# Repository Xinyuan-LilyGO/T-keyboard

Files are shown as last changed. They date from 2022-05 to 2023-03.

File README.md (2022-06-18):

<h1 align = "center">🌟LILYGO T-keyboard🌟</h1>

## **English | [中文](./README_CN.MD)**

<h3 align = "left">Default some custom functions:</h3>

| keyboard input | Trigger |
| :---: | :---: |
| Left shit | Shift |
| Right shit | Toggle case locking |
| sym | Enter numbers and characters (only triggered once, not locked) |
| alt+left shit  | ctrl+shift(Switch the input method) |
| alt+b | Change keyboard backlight status |
| ... | More custom features can be modified source code implementation, or feedback |

<h3 align = "left">Quick start:</h3>

**USE Arduino IDE**

1. Install the current upstream Arduino IDE at the 1.8 level or later. The current version is at the [Arduino website](http://www.arduino.cc/en/main/software).
2. Start Arduino and open Preferences window. In additional board manager add url: https://raw.githubusercontent.com/espressif/arduino-esp32/gh-pages/package_esp32_index.json .separating them with commas.
3. Select Tools -> Board -> ESP32C3 Dev Module
4. If you do not have a driver installed, you need to install it (Window:ch341ser2.exe, MAC:ch34x_mac_driver_v1.6.zip [New driver reference](https://github.com/LilyGO/LILYGO-T-OI/issues/3#issuecomment-907645945 ))
5. Need to install the following dependencies
     - [ESP32-BLE-Keyboard](https://github.com/T-vK/ESP32-BLE-Keyboard/tree/0.3.0)
     - [T-0.99TFT](https://github.com/Xinyuan-LilyGO/T-0.99TFT)

**USE PlatformIO**

1. Install[VSCODE](https://code.visualstudio.com/)and[Python](https://www.python.org/)
2. Search for the PlatformIO plug-in in the VSCODE extension and install it.
3. After the installation is complete and the reload is completed, there will be a small house icon in the lower left corner. Click to display the Platformio IDE home page
4. Go to file - > Open folder - > Select the LilyGO-T-Keybord folder and click the (√) symbol in the lower left corner to compile (→) for upload.

<h3 align = "left">Product 📷:</h3>

|  Product | Product  Link |
| :---: | :---: |
| T-keyboard | [AliExpress](https://pt.aliexpress.com/item/1005004182998265.html) |

## Matters need attention 
1. Do not set the screen backlight to too high, which may cause overexposure

## Pinout

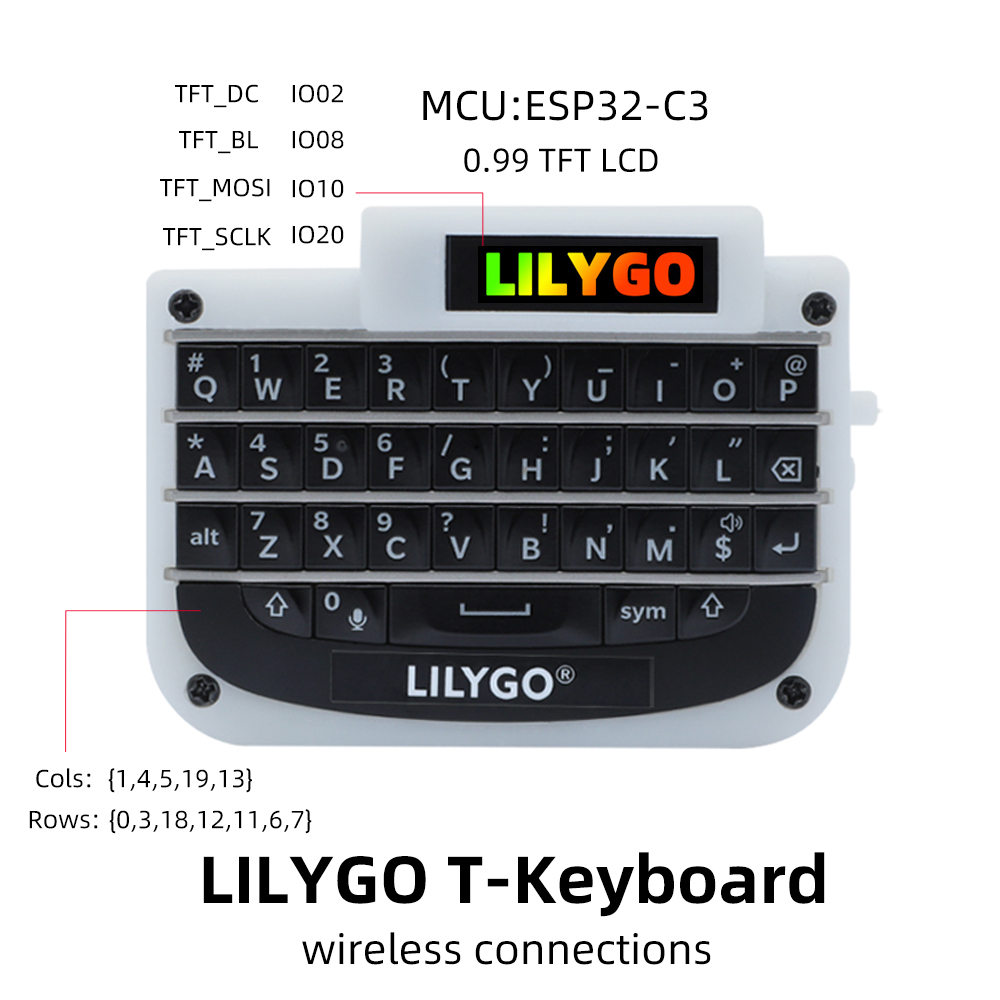
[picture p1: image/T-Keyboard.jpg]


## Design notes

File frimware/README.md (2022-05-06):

<h1 align = "center">🌟LILYGO T-keyboard🌟</h1>

[Flash Download Tool](https://www.espressif.com/en/support/download/other-tools)

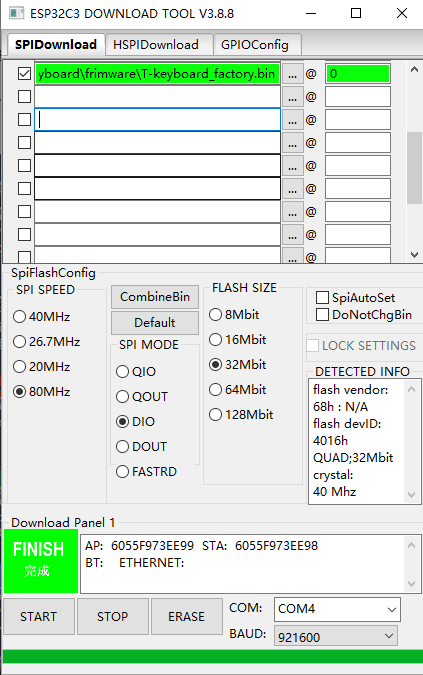
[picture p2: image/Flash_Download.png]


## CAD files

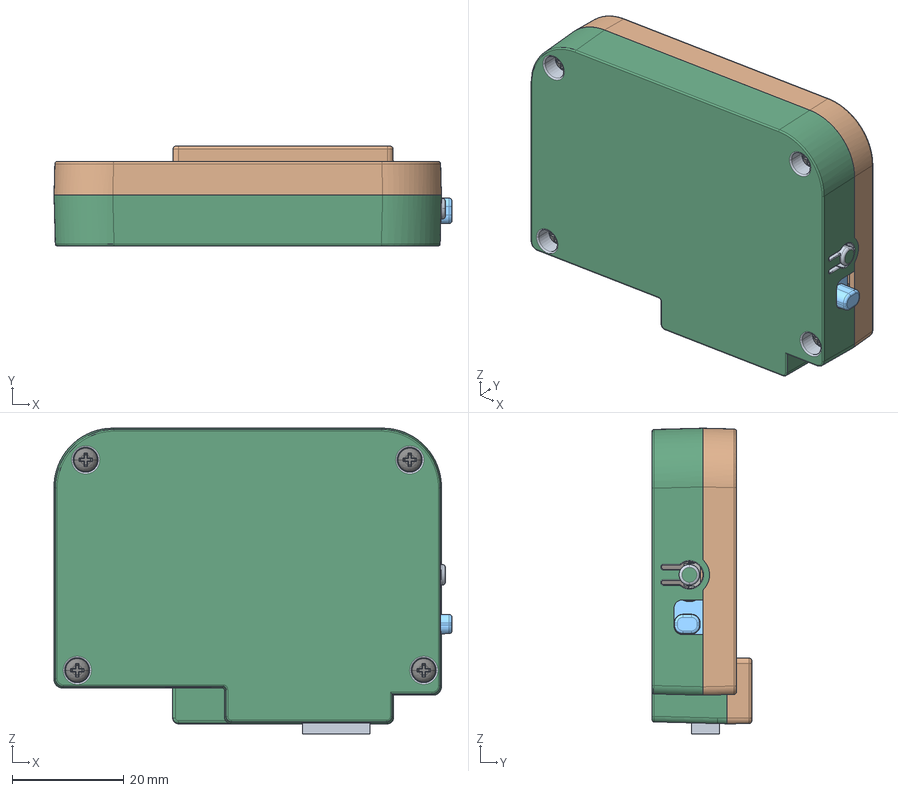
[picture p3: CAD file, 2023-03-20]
3D_file/T-Keyboard.stp
71.1 x 17.8 x 54.6 mm
020_WATCK_KEY_ACOV_2_3
021_WATCK_KEY_BCOV_2_6
022_WATCK_KEY_CCOV_2_1
BRASS_NUTS-2_5_3-2_1 x 4
SCREW_M2-8_1 x 4
MANIFOLD_SOLID_BREP_216_1_1
MANIFOLD_SOLID_BREP_217_1_1
MANIFOLD_SOLID_BREP_220_2_1
WATCH_KEY_LCD_SLOT-B
WATCH_KEY_LCD_SLOT-A

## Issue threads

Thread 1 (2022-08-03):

PCB schematic?

jaksatomovic, 2022-08-03:

SkUrRiEr, 2023-03-13:
As far as I can tell, no schematic has been released anywhere.

This _seems_ to be loosely based on the [T-OI-PLUS](https://github.com/Xinyuan-LilyGO/LilyGo-T-OI-PLUS/) which does have a released schematic.

Based on some brief research, the major changes seem to be:
1. Completely eliminating the analogue input circuitry
2. Connecting almost all the I/O pins to the keyboard, i.e. 12 I/O pins hooked up directly to the columns and rows, and pin 9 hooked to some circuitry to drive the keyboard's backlight
3. Connecting the remaining I/O pins to the [T-0.99-TFT module](https://github.com/Xinyuan-LilyGO/T-0.99TFT) which also contains the expansion connector

The ESP32-C3 has a grand total of 22 available I/O pins including 4-7 for the program flash and 2 for the serial port, leaving a grand total of 13-16 usable pins. We have assignments for 17.

This means that there are simply no I/O pins left to dedicate to the keyboard's microphone or the battery management. Which means that the only way those could be connected to the microcontroller would be if they're doing something _seriously_ tricky to hook these functions up to one of the ADC pins: 0-5.

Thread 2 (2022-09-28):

Compiling error. Can you provide hardware details

vcchm, 2022-09-28:
Hello !

The device is not working after compiling for ESP32C3 Dev module. Can you provide more information about the board : flash size (4 Mb ? 8 Mb) - under arduino you get an error when startipn the module if the flash size is not exactly correct ? Wiring (i want to program a wakeup function, but for this I need to now what wakeup pin i can use) ? Thanks in advance

LilyGO, 2022-09-28:
Hello .Flash size 4MB. No extra pins

vcchm, 2022-09-28:
Thanks ! Could you share the info & wiring of ESP32 on the main page ? Would help lots of users.

LilyGO, 2022-09-28:
https://github.com/Xinyuan-LilyGO/T-keyboard#pinout

Closed 2022-11-02.

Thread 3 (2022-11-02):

Windows 10 & 11 work fine, but challenges connecting to Android

vcchm, 2022-11-02:
Hi ! I compiled the code, pairing & sending keys work well with a PC Windows 10 or 11, but I can't pair with an Android device (Samsung note 20). Here are screenshots. Message reads "Paring with the device impossible. Please ensure that the device is ready for pairing.".

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

LilyGO, 2022-11-03:
Hello. Is it possible to pair with this [firmware?](https://github.com/Xinyuan-LilyGO/T-keyboard/releases/download/T-KeyboardV1.0.0/T-keyboard__factory_1.0.0.bin)

vcchm, 2022-11-03:
I only can flash an arduino sketch, not a binary but if i test the original firmware provided with a new keyboard, it pairs after a couple of atempts. Can you tell me the precise version of the blekeyboard you are using ? It seems that they did modifications that makes it not working for Android in the latest versions...

LilyGO, 2022-11-03:
In the lib

vcchm, 2022-11-03:
No the latesy version is not working - you compiled the code with a former version but you do not tell which version you used in the github. Can you tell me (and other users) the precise version number you used ? The latest has a bug, and i could not find the working version

LilyGO, 2022-11-04:
The library has been modified. It is not a certain version

vcchm, 2022-11-04:
I don't think it has been modified. What happens is that your page should mention the VERSION you are using so that we are sure we use the working version. Do you know what the version is or at least WHEN you compiled the code so that I can use this date's latest version ?

Closed 2022-11-04.

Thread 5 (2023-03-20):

Drivers

allthemod, 2023-03-20:
what do you mean by this(in step 4 for the arduino ide):
If you do not have a driver installed, you need to install it (Window:ch341ser2.exe, MAC:ch34x_mac_driver_v1.6.zip https://github.com/LilyGO/LILYGO-T-OI/issues/3#issuecomment-907645945)

how to install it?
and can i use it on other versions of esp32?

SkUrRiEr, 2023-04-08:
The driver being requested here is the driver for the USB-serial chip, which is a CH340K or equivalent chip.

Closed 2023-04-19.

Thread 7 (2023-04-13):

Unable to compile BLE_Keyboard

Chanete, 2023-04-13:
Hi, I'm trying to compile the BLE_Keyboard  sample.
I followed the instructions (installed latest arduino ide 2.0.4, installed latest usb driver, addded board, selected ESP32C, added the two libs and compile and upload.

Everything seems to be OK, but the keyboard is now locked (nothing on screen)
This is my compiler output.

Thx for your help

`Sketch uses 988408 bytes (75%) of program storage space. Maximum is 1310720 bytes.
Global variables use 57316 bytes (17%) of dynamic memory, leaving 270364 bytes for local variables. Maximum is 327680 bytes.
esptool.py v4.5.1
Serial port COM9
Connecting....
Chip is ESP32-C3 (revision v0.3)
Features: WiFi, BLE
Crystal is 40MHz
MAC: 7c:df:a1:d5:ae:d8
Uploading stub...
Running stub...
Stub running...
Changing baud rate to 921600
Changed.
Configuring flash size...
Flash will be erased from 0x00000000 to 0x00003fff...
Flash will be erased from 0x00008000 to 0x00008fff...
Flash will be erased from 0x0000e000 to 0x0000ffff...
Flash will be erased from 0x00010000 to 0x00108fff...
Compressed 13152 bytes to 9473...
Writing at 0x00000000... (100 %)
Wrote 13152 bytes (9473 compressed) at 0x00000000 in 0.4 seconds (effective 267.3 kbit/s)...
Hash of data verified.
Compressed 3072 bytes to 146...
Writing at 0x00008000... (100 %)
Wrote 3072 bytes (146 compressed) at 0x00008000 in 0.1 seconds (effective 329.8 kbit/s)...
Hash of data verified.
Compressed 8192 bytes to 47...
Writing at 0x0000e000... (100 %)
Wrote 8192 bytes (47 compressed) at 0x0000e000 in 0.2 seconds (effective 435.7 kbit/s)...
Hash of data verified.
Compressed 1019904 bytes to 553498...
Writing at 0x00010000... (2 %)
Writing at 0x0001b21c... (5 %)
Writing at 0x00028388... (8 %)
Writing at 0x000352d2... (11 %)
Writing at 0x000403fd... (14 %)
Writing at 0x00046293... (17 %)
Writing at 0x0004cbef... (20 %)
Writing at 0x000540c8... (23 %)
Writing at 0x0005a325... (26 %)
Writing at 0x0006083a... (29 %)
Writing at 0x00067dec... (32 %)
Writing at 0x0006e40f... (35 %)
Writing at 0x00074d16... (38 %)
Writing at 0x0007af53... (41 %)
Writing at 0x00081230... (44 %)
Writing at 0x000886be... (47 %)
Writing at 0x0008ee4a... (50 %)
Writing at 0x0009696a... (52 %)
Writing at 0x0009d20d... (55 %)
Writing at 0x000a34e9... (58 %)
Writing at 0x000aa543... (61 %)
Writing at 0x000b1eab... (64 %)
Writing at 0x000baa52... (67 %)
Writing at 0x000c14c2... (70 %)
Writing at 0x000c7d5e... (73 %)
Writing at 0x000ceaf3... (76 %)
Writing at 0x000d5047... (79 %)
Writing at 0x000db14a... (82 %)
Writing at 0x000e0eda... (85 %)
Writing at 0x000e75b5... (88 %)
Writing at 0x000eec7c... (91 %)
Writing at 0x000f8596... (94 %)
Writing at 0x000fdd96... (97 %)
Writing at 0x00103f19... (100 %)
Wrote 1019904 bytes (553498 compressed) at 0x00010000 in 13.7 seconds (effective 597.0 kbit/s)...
Hash of data verified.

Leaving...
Hard resetting via RTS pin...`

allthemod, 2023-04-14:
I had the same problem.
It's like you can't write to there.
Anyway I just used the download flash tools to flash the firmware bin file into the esp.
If you wanna to customize it idk.
But if you wanna to return it back to the default I can help you.

Chanete, 2023-04-19:
I've found a workaround that works, I'm using platformIO instead of Arduino IDE and now I can compile and modify without problems.

Probably there is some setup in arduino ide config missing in the docs.

Thx anyway @allthemod  for your offer.

allthemod, 2023-04-19:
Well I didn't know that.
This is also very handy to me so thank you and have a great day @Chanete .

copykatze, 2023-05-05:
I had the same problem and solved it by changing the "flash mode" in the Arduino IDE from "QUI" to "DOUT". Flashing seems to work fine now. Cheers.

allthemod, 2023-05-05:
Thanks and have a great day.

Adarkk, 2024-06-25:
Hey can someone help me to get taht stuff back to work ?

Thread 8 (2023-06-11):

display initialization problem

copykatze, 2023-06-11:
Sometimes the display does not initialize properly, it will only show some thin lines or a light grey background and it can't be written to by the program. Reseting the device by on/off or the reset button helps sometimes after a few tries, sometimes it seems to need "off-time", but I could not really figure out when it does not work and what gets it back on track. It is really unreliable like this. What might cause this weirdness?

I found that when I enabled core debug level, at `TFT_099.begin();` I get this log:

```
12:51:23.065 -> [   174][E][esp32-hal-gpio.c:102] __pinMode(): Invalid pin selected
12:51:23.097 -> [   174][E][esp32-hal-gpio.c:102] __pinMode(): Invalid pin selected
12:51:23.097 -> [   177][E][esp32-hal-gpio.c:102] __pinMode(): Invalid pin selected
12:51:23.195 -> [   283][E][esp32-hal-spi.c:227] spiAttachMISO(): SPI Does not have default pins on ESP32C3!
```

Could this be the cause of it? But those error messages will also be in the logs when it works. No idea how to debug this any further... :(

Any help appreciated, thanks and cheers!

copykatze, 2023-06-11:
In `TFT_GC9D01N.h`I found

```
#define TFT_MISO  -1
#define TFT_MOSI  10//21
#define TFT_SCLK  20//22
#define TFT_CS    -1//18  // Chip select control pin
#define TFT_DC    2  // Data Command control pin
#define TFT_RST   -1//27
#define TFT_BL    8//4

/*
#define TFT_MISO  -1
#define TFT_MOSI  21
#define TFT_SCLK  22
#define TFT_CS    18  // Chip select control pin
#define TFT_DC    2  // Data Command control pin
#define TFT_RST   27
#define TFT_BL    23//4
*/
```
It seems strange to me that TFT_MISO, TFT_CS and TFT_RST. are all defined -1 (does that mean "undefined?) and I wonder what that commented block of alternative definitions is all about...

copykatze, 2023-06-11:
Another observation: what seems to help is to power it on while connected to usb c power and then pressing the reset button. This method does not help without the device being plugged in.

So maybe the small battery does not provide enough power for the (tiny) display? But on the other side, the grey screen happens also while powering on when plugged in sometimes...

alejovargas78, 2024-01-22:
Hello, I had the same problem, the solution is simple.

Open the library TFT_GC9D01N.cpp and disable the following lines

int TFT_GC9D01N_Class::begin()
{
     pinMode(TFT_BL, OUTPUT);
     pinMode(TFT_SCLK, OUTPUT);
     //pinMode(TFT_MISO, OUTPUT);
     pinMode(TFT_MOSI, OUTPUT);
     pinMode(TFT_DC, OUTPUT);
     //pinMode(TFT_CS, OUTPUT);
     //pinMode(TFT_RST, OUTPUT);

Greetings from Bogota Col.

copykatze, 2024-01-22:
Wow, thank you so much, @alejovargas78 !! I did not get an external display working (yet), but I am happy to hear that it seems to be possible :)

Could you share with me which kind of display you were able to connect and how you wired it exactly?

I am trying with a ili9341 ("2.2 TFT SPI 240*320") display.

My wiring, after editing the library according to your suggestion, is

Display <-> T-Keyboard

SDO (MISO) <->
LEDK <->LED
SCK <-> SCL
SDI (MOSI) <-> SDA
D/C <-> D/C
RESET <->
CS <->
GND <-> GND
VCC <-> +3.3V

Running the [TFT_Demo.ino](https://github.com/Xinyuan-LilyGO/T-keyboard/blob/main/lib/T-0.99TFT/examples/TFT_Demo/TFT_Demo.ino) example, the display just  flickers a bit.

One error I see on the serial monitor is:
`[   192][E][esp32-hal-spi.c:227] spiAttachMISO(): SPI Does not have default pins on ESP32C3!`

It would be so awesome if I could finish this project afterall :)

copykatze, 2024-01-23:
Unfortunately, I have the same result/problem with the adjustments in the library, still thanks for the suggestion!

alejovargas78, 2024-09-07:
pinMode(TFT_MOSI, OUTPUT);
    pinMode(TFT_DC, OUTPUT);
    pinMode(TFT_BL, OUTPUT);
    pinMode(TFT_SCLK, OUTPUT);
    ledcSetup(1, 1000, 10);
    ledcAttachPin(TFT_BL, 1);
    ledcWrite(1, 0);
    delay(100);

    SPI.begin(TFT_SCLK, TFT_MISO, TFT_MOSI, TFT_CS);

    int i = 2;
    while (i--) {
        lcd_init();
        delay(200); /* code */
    }
    ledcWrite(1, 220);//开启背光

    return 1;

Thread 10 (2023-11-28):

working like a Blackberry Keyboard

Flexmaen, 2023-11-28:
Hi!

Great hardware, however for me it's a bit confusing that this keyboard does look like a Blackberry-Keyboard, but doesn't work like one.

This means:
- ALT-Key usually does all the other signs shown on the keyboard, not sym.
Numbers, ,?/().,' etc. is all done by alt key.
- Alt-Key works as long as you hold it down, that means just jold it down and type numbers instead having to press it every time you write a number.
- Sym key can be configured for international options. E.g. sym+u = ü.
- right shift key can be configured as normal shift key or as ctrl-key which means that witch ctrl+c and v you can copy and paste things. (maybe it also makes sense to use the sym-key here instead).

slayinturds, 2023-12-21:
So it does work like a blackberry keyboard or not exactly? It's been ages since I had my bold 5000, and I'm just trying to have that magic back via Bluetooth. Is this the device for the job?

Flexmaen, 2023-12-22:
It doesn't even come close to a Blackberry keyboard although it is a keyboard of the Q10.
But the way it works is completely messed up.
Like I said: Alt and Sym Key are confused, holding down the alt/sym-Key has no effect, so typing numbers is a pain.

So if you ever used a Blackberry keyboard, then this device is a big disappointment. Depending on what you need this for, you might take a look on the BBQ20KBD or Help2Type.

However, the good thing: Most things could be fixed via software, that's why I opened this issue here.

slayinturds, 2023-12-24:
That makes sense, thanks for the suggestion. Hopefully they figure out the software since I already ordered one

zenkalia, 2023-12-27:
I just bought one because fixing some keybinds seems easier than taking the BBQ and connecting it to a battery and BLE module for my use case (typing with baby asleep on me).

I'll be taking a look at this when mine comes. At a glance, the right shift seems easiest to fix. Other language support seems daunting and the other modifiers seem somewhere in between. Thankfully the shift issue is the most important to me!

slayinturds, 2023-12-27:
I hate it. I'll be taking it back and if they refuse I'll go to their
office in Gainesville FL. I live there conincidentally. If it's possible
I'll share feeeback directly. The keys for one are at the same level as the
case and the trim pieces, making it so difficult to land on the keys and
not the case elements when inputting characters. That is such a no brainer
to fix and figure out when prototyping

On Wed, Dec 27, 2023, 11:28 AM Mike Kendall ***@***.***>
wrote:

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

zenkalia, 2023-12-28:
That's too bad! Mine hasn't come yet and the ergonomics of those bars does worry me. This is the best option out there since the Help2Type is so expensive that you might as well buy a palmtop computer.

slayinturds, 2023-12-28:
Yeah it is.
Honestly, I'm interested in this one next that you suggested:
https://shop.pimoroni.com/products/bbq20-keyboard-with-trackpad-usb-i2c-pmod?variant=39913457188947

On Thu, Dec 28, 2023 at 2:43 PM Mike Kendall ***@***.***>
wrote:

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

Flexmaen, 2023-12-29:
What are you planning to use it for? I didn't test the BBQ20, but I'm currently using the Help2Type for my phone. The flip-mechanism works better than I thought it will. The downside compared to a Blackberry keyboard is that keys are harder to press, and the lack of the ctrl-key. The layout is a bit different and some things like the delete key need a bit to adjust. But otherwise the layout is in full accordance with the virtual keyboards that gboard or iOS provide, so it's not a stupid change in the layout. All in all, for me it was worth buying it.

I'm using the T-Keyboard for my Fire-TV now. For occasional typing it's better than the remote control, but that's it.
Sure this is a rather cheap solution, but now I'm not the only one who is surprised how bad a Blackberry keyboard can be if you get the software and the case wront.

slayinturds, 2023-12-29:
With the phone propped up by the kickstand ring on the back of the phone,
and the keypad detached in my hand, I thought I could type emails better
when away from my computer. That may not be the case. I used to be able to
type for a long time for emails with my BB5000, but I'm probably chasing a
time that is irrelevant. I was thinking about your situation and not
wanting to make sound the other day, because I just purchased a Logitech
wireless mouse that makes no clicking sound. I thought I'd hate it but
actually I love it; the M650. I see your uses, that makes sense. The
Help2type, looks ergonomic but I could not deal with the hard key pressing.
I'm so picky with this stuff, I don't mind searching for the perfect
solution to all my problems.

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

zenkalia, 2024-01-05:
Just opened my first PR to this end: https://github.com/Xinyuan-LilyGO/T-keyboard/pull/11

Next comes swapping `alt` and `sym` and adding arrow keys. I'm thinking sym + WASD because it's just too painful not having arrow keys.

And a note on ergonomics: I don't mind the bars between the rows but the case itself IS a little too tall. It should have had a bevel or something because as it is, the keys that are near the case are a little difficult to press.

zenkalia, 2024-01-05:
Alright I got a little overzealous last night and finished it. ALT and SYM swapped and WASD arrow keys:

https://github.com/zenkalia/T-keyboard/tree/alt_sym_arrows

This is what I'm running on my T-Keyboard right now and it's much more fluid than the default behavior. 👍

ibrand, 2024-01-05:
@zenkalia very cool, I just got my T-keyboard in the mail, started searching around for this and was lucky enough to find your comment from just a few hours ago. If I were to use your fork, would I follow the Arduino IDE setup flow and then import your example files? How did you set your keyboard up with alternative code?

thanks for your work on this 🎉

zenkalia, 2024-01-06:
I used the vs code instructions. The arduino IDE was way less fleshed out from what I could tell.

There's also a necessary driver for pushing to the serial port of the device (chx something) which was terrifying to install but it worked. Would love to have that come with the PlayformIO board config or have LILYGO bless it in the readme.

zenkalia, 2024-01-06:
Yeah I've been thinking about how to best handle custom keys since they're different for everyone. I think the right move is to have an extra mapping matrix for symbols that people can modify in code. If you leave a given cell empty then it can be a fully custom function (see backlight toggle).

If there are ever enough users to justify menus and stuff then we'll need to change from the 8x20 font to an 8x10 so that we can display 4 rows rather than 2... Also need a better way to render stuff to the screen since the TFT library isn't going to give us scrolling, for example.

I plan on adding the symbol mapping matrix later today since it's a more elegant and extensible way to add arrow keys.

After that on my todo list is using both rows on the TFT screen when typing.

Also the lack of key repeat is driving me nuts!

zenkalia, 2024-01-14:
@Flexmaen So I did put in a mapping table for the sym key until I realized that those other special characters don't exist in the font. Also I have no idea how this font works to add them. 🤔

zenkalia, 2024-01-14:
Ok. I know how the font works. It's kind of bonkers.

So the font file is a bunch of bitmaps. Here's A: https://github.com/Xinyuan-LilyGO/T-keyboard/blob/main/lib/T-0.99TFT/src/Fonts.h#L38-L39 each hex pair is a row in the character. Each bit is a pixel being on or off.

We write text to the screen using `TFT_099.DispStr`. Each character in that function is then converted from ascii value to "ord" like we see in that font file. The helper function that does that is here: https://github.com/Xinyuan-LilyGO/T-keyboard/blob/main/lib/T-0.99TFT/src/TFT_GC9D01N.cpp#L533-L550 .

So, for every character that you want to add, you have to add it to this conversion helper and to the font bitmask. How much work would it be to make this font array indexed by ascii value instead of "ord" value? 🤯

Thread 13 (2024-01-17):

Any reason why this won't connect to an Apple Watch?

edwardrossi, 2024-01-17:
As far as I know, Bluetooth keyboard's are compatible with Apple Watch, yet I cannot connect the T-keyboard. It doesn't even appear in the Bluetooth devices when in pairing mode.

It's a Series 5 running WatchOS 10.2.

On a side note, it appears and connect flawlessly to iPhone.

For context, I bought the T-Board to connect to my Apple Watch to see how it performs as a dumbphone.
If it passes proof of concept, I will play with some designs and 3D print a case integrating the Apple Watch body and the T-board into a single integrated device.

Any ideas?

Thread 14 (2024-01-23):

How to connect an external display?

copykatze, 2024-01-23:
I could not get an external display working on the "expansion interface". What kind of display can be used and how to wire it?

I am trying with a ili9341 ("2.2 TFT SPI 240*320") display, which I can get working without any problem on other esp/arduino boards, so the display is not broken.

My wiring is

Display <-> T-Keyboard

SDO (MISO) <->
LEDK <->LED
SCK <-> SCL
SDI (MOSI) <-> SDA
D/C <-> D/C
RESET <->
CS <->
GND <-> GND
VCC <-> +3.3V

Running the [graphicstest.ino](https://github.com/adafruit/Adafruit_ILI9341/blob/master/examples/graphicstest/graphicstest.ino) example, the display just  flickers a bit and seems to crash very early, as it does not even Serial.println("ILI9341 Test!"). One error I see on the serial monitor is:

`[   192][E][esp32-hal-spi.c:227] spiAttachMISO(): SPI Does not have default pins on ESP32C3!`

Any help on debugging this (or telling me any stupid mistakes I made) would be highly appreciated, also any info that this has been successfully done by anyone :)

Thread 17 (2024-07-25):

Wont stay connected, and does not work at all under Windows 10

JimDrewGH, 2024-07-25:
So, I got the LilyGO T-Keyboard, powered it on and went to the BLE config under Windows 10 and was able to pair the device.  After that, there is no "keyboard" functionality.  The device also will periodically disconnect and say "Wait bluetooth...." and then finally connect.

I plugged the T-Keyboard into a USB port and pulled up a terminal program and see this constantly (as fast as the serial console will display at 115200 baud):

[2319993][E][BLECharacteristic.cpp:537] notify(): << esp_ble_gatts_send_ notify: rc=-1 Unknown ESP_ERR error

So, does this mean that the T-Keyboard is not compatible with Windows?  I tried the PC motherboard's built-in Bluetooth and an external Bluetooth (USB) device, and both had the same issue.  Ironically, this works flawless with my iPhone13 so I know the T-Keyboard hardware is functional.  This seems like a problem with interfacing to Windows.  Does anyone know why?

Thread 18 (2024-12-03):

language change on PC with T-Keyboard.

Stigjs, 2024-12-03:
Hello
I've never done coding in my life, like VS CODE, but I believe in ChatGPT
I bought a LILYGO T-Keyboard.

I tried to add language conversion (English/Korean) function using GitHub's firmware data and VS code,

The code that ChatGPT corrected keeps making errors..

1. Change the language to the left alt key and enter key. (You can't change the line when you enter.)
2. Set Backlight Time
Backlight off if not entered for 10 seconds. On input back on
3. Delete letters when you press the Backspace key
I don't want to press it repeatedly..
4. Make sure you enter numbers/periods with the left shift key. I asked for these four functions

I kept erasing the original code, so I couldn't do it
I downloaded VS and installed Platformio through ChatGPT
I can't use it because I can't change the language. Please help me..
What should I do?

Stigjs, 2024-12-03:
the Code is..
#define TFT_HIGH  40
#define TFT_WIDE 160
#define GAP 8
#define keyborad_BL_PIN  9

#include "Arduino.h"
#include <SPI.h>
#include "img.h"
#include <TFT_GC9D01N.h>
#include <BleKeyboard.h>

TFT_GC9D01N_Class TFT_099;
BleKeyboard bleKeyboard("T-Keyboard", "ESPRESSIF", 100);

byte rows[] = {0, 3, 18, 12, 11, 6, 7};
const int rowCount = sizeof(rows) / sizeof(rows[0]);

byte cols[] = {1, 4, 5, 19, 13};
const int colCount = sizeof(cols) / sizeof(cols[0]);

bool keys[colCount][rowCount];
bool lastValue[colCount][rowCount];
bool changedValue[colCount][rowCount];

char keyboard[colCount][rowCount];
char keyboard_symbol[colCount][rowCount];

bool symbolSelected = false;
bool isEnglish = true; // 언어 전환 상태
bool alt_active = false;
int OffsetX = 0;
bool keyborad_BL_state = true;
bool display_connected = true;
bool case_locking = false;

unsigned long previousMillis_1 = 0;
unsigned long previousMillis_2 = 0;
const long backlight_off_time = 10000; // 10초
const long display_Wait_blue_time = 2000;

void readMatrix();
bool keyPressed(int colIndex, int rowIndex);
bool keyActive(int colIndex, int rowIndex);
bool isPrintableKey(int colIndex, int rowIndex);
void printMatrix();
void set_keyborad_BL(bool state);
void clear_sccreen();

void setup() {
    Serial.begin(115200);
    Serial.println("Setup started");

    // 키보드 배열 초기화
    keyboard[0][0] = 'q';
    keyboard[0][1] = 'w';
    keyboard[0][2] = '\0'; // Symbol
    keyboard[0][3] = 'a';
    keyboard[0][4] = '\0'; // ALT
    keyboard[0][5] = ' ';
    keyboard[0][6] = '\0'; // Mic

    keyboard[1][0] = 'e';
    keyboard[1][1] = 's';
    keyboard[1][2] = 'd';
    keyboard[1][3] = 'p';
    keyboard[1][4] = 'x';
    keyboard[1][5] = 'z';
    keyboard[1][6] = '\0'; // Left Shift

    keyboard[2][0] = 'r';
    keyboard[2][1] = 'g';
    keyboard[2][2] = 't';
    keyboard[2][3] = '\0'; // Right Shift
    keyboard[2][4] = 'v';
    keyboard[2][5] = 'c';
    keyboard[2][6] = 'f';

    keyboard[3][0] = 'u';
    keyboard[3][1] = 'h';
    keyboard[3][2] = 'y';
    keyboard[3][3] = '\0'; // Enter
    keyboard[3][4] = 'b';
    keyboard[3][5] = 'n';
    keyboard[3][6] = 'j';

    keyboard[4][0] = 'o';
    keyboard[4][1] = 'l';
    keyboard[4][2] = 'i';
    keyboard[4][3] = '\0'; // Backspace
    keyboard[4][4] = '$';
    keyboard[4][5] = 'm';
    keyboard[4][6] = 'k';

    delay(500);
    pinMode(keyborad_BL_PIN, OUTPUT);
    set_keyborad_BL(keyborad_BL_state);

    bleKeyboard.begin();

    for (int x = 0; x < rowCount; x++) {
        pinMode(rows[x], INPUT);
    }

    for (int x = 0; x < colCount; x++) {
        pinMode(cols[x], INPUT_PULLUP);
    }

    TFT_099.begin();
    TFT_099.backlight(50);
    TFT_099.DispColor(0, 0, TFT_WIDTH, TFT_HEIGHT, BLACK);
    TFT_099.DispStr((char*)"Setup completed", 0, 2, WHITE, BLACK); // char*로 캐스팅
    Serial.println("Setup completed");
}

void loop() {
    if (bleKeyboard.isConnected()) {
        readMatrix();

        // ALT(4,0) + ENTER(3,3) 언어 전환
        if (keyActive(4, 0) && keyPressed(3, 3)) {
            isEnglish = !isEnglish;
            TFT_099.DispStr(isEnglish ? (char*)"English Mode" : (char*)"Korean Mode", 0, 2, WHITE, BLACK);
            Serial.println(isEnglish ? "English Mode" : "Korean Mode");
            delay(500);
        }

        // 백라이트 제어
        if (millis() - previousMillis_1 > backlight_off_time) {
            TFT_099.backlight(0);
        }

        printMatrix();

        // Backspace 키 동작
        if (keyPressed(4, 3)) {
            if (OffsetX > 0) OffsetX -= GAP;
            TFT_099.DispColor(0, OffsetX, TFT_HIGH, TFT_WIDE, BLACK);
            bleKeyboard.press(KEY_BACKSPACE);
            bleKeyboard.releaseAll();
        }

        // Left Shift 키로 특수문자 입력
        if (keyActive(1, 6)) {
            case_locking = true;
        } else {
            case_locking = false;
        }

    } else {
        if (millis() - previousMillis_2 > display_Wait_blue_time) {
            TFT_099.DispStr((char*)"Waiting for Bluetooth...", 0, 2, WHITE, BLACK); // char*로 캐스팅
            display_connected = true;
            previousMillis_2 = millis();
        }
    }
}

void readMatrix() {
    for (int colIndex = 0; colIndex < colCount; colIndex++) {
        for (int rowIndex = 0; rowIndex < rowCount; rowIndex++) {
            bool currentValue = digitalRead(cols[colIndex]) == LOW && digitalRead(rows[rowIndex]) == LOW;
            if (currentValue != lastValue[colIndex][rowIndex]) {
                changedValue[colIndex][rowIndex] = true;
            } else {
                changedValue[colIndex][rowIndex] = false;
            }
            keys[colIndex][rowIndex] = currentValue;
            lastValue[colIndex][rowIndex] = currentValue;
        }
    }
}

bool keyPressed(int colIndex, int rowIndex) {
    return changedValue[colIndex][rowIndex] && keys[colIndex][rowIndex];
}

bool keyActive(int colIndex, int rowIndex) {
    return keys[colIndex][rowIndex];
}

bool isPrintableKey(int colIndex, int rowIndex) {
    return keyboard[colIndex][rowIndex] != '\0';
}

void printMatrix() {
    for (int rowIndex = 0; rowIndex < rowCount; rowIndex++) {
        for (int colIndex = 0; colIndex < colCount; colIndex++) {
            if (keyPressed(colIndex, rowIndex)) {
                String key = String(keyboard[colIndex][rowIndex]);
                if (case_locking) key.toUpperCase();
                Serial.print(key);
                bleKeyboard.print(key);
                OffsetX += GAP;
                if (OffsetX > 160) {
                    OffsetX = 0;
                    clear_sccreen();
                }
            }
        }
    }
}

void set_keyborad_BL(bool state) {
    digitalWrite(keyborad_BL_PIN, state);
}

void clear_sccreen() {
    TFT_099.DispColor(0, 0, TFT_HIGH, TFT_WIDE, BLACK);
    OffsetX = 0;
}

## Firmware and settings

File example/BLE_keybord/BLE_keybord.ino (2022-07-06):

#define TFT_HIGH  40
#define TFT_WIDE 160
#define GAP 8
#define keyborad_BL_PIN  9


#include "Arduino.h"
#include <SPI.h>
#include "img.h"
#include<TFT_GC9D01N.h>
TFT_GC9D01N_Class TFT_099;

#include <BleKeyboard.h>
BleKeyboard bleKeyboard("T-Keyboard", "ESPRESSIF", 100);

byte rows[] = {0, 3, 18, 12, 11, 6, 7};
const int rowCount = sizeof(rows) / sizeof(rows[0]);


byte cols[] = {1, 4, 5, 19, 13};
const int colCount = sizeof(cols) / sizeof(cols[0]);

bool keys[colCount][rowCount];
bool lastValue[colCount][rowCount];
bool changedValue[colCount][rowCount];

char keyboard[colCount][rowCount];
char keyboard_symbol[colCount][rowCount];


bool symbolSelected;
int OffsetX = 0;
uint16_t flow_i = 0;
bool keyborad_BL_state = true;
bool display_connected = true;  //The bluetooth connection is displayed on the screen
bool case_locking = false;
bool alt_active = false;
unsigned long previousMillis_1 = 0; //Millisecond time record
unsigned long previousMillis_2 = 0; //Millisecond time record
const long backlight_off_time = 20000;       //Turn off the screen backlight
const long display_Wait_blue_time = 2000;       //The screen shows waiting for bluetooth connection

void readMatrix();
bool keyPressed(int colIndex, int rowIndex);
bool keyActive(int colIndex, int rowIndex);
bool isPrintableKey(int colIndex, int rowIndex);
void printMatrix();
void set_keyborad_BL(bool state);
void clear_sccreen();

void setup()
{
    Serial.begin(115200);
    Serial.printf("setup \n");
    keyboard[0][0] = 'q';
    keyboard[0][1] = 'w';
    keyboard[0][2] = NULL; // symbol
    keyboard[0][3] = 'a';
    keyboard[0][4] = NULL; // ALT
    keyboard[0][5] = ' ';
    keyboard[0][6] = NULL; // Mic

    keyboard[1][0] = 'e';
    keyboard[1][1] = 's';
    keyboard[1][2] = 'd';
    keyboard[1][3] = 'p';
    keyboard[1][4] = 'x';
    keyboard[1][5] = 'z';
    keyboard[1][6] = NULL; // Left Shift

    keyboard[2][0] = 'r';
    keyboard[2][1] = 'g';
    keyboard[2][2] = 't';
    keyboard[2][3] = NULL; // Right Shit
    keyboard[2][4] = 'v';
    keyboard[2][5] = 'c';
    keyboard[2][6] = 'f';

    keyboard[3][0] = 'u';
    keyboard[3][1] = 'h';
    keyboard[3][2] = 'y';
    keyboard[3][3] = NULL; // Enter
    keyboard[3][4] = 'b';
    keyboard[3][5] = 'n';
    keyboard[3][6] = 'j';

    keyboard[4][0] = 'o';
    keyboard[4][1] = 'l';
    keyboard[4][2] = 'i';
    keyboard[4][3] = NULL; // Backspace
    keyboard[4][4] = '$';
    keyboard[4][5] = 'm';
    keyboard[4][6] = 'k';

    keyboard_symbol[0][0] = '#';
    keyboard_symbol[0][1] = '1';
    keyboard_symbol[0][2] = NULL;
    keyboard_symbol[0][3] = '*';
    keyboard_symbol[0][4] = NULL;
    keyboard_symbol[0][5] = NULL;
    keyboard_symbol[0][6] = '0';

    keyboard_symbol[1][0] = '2';
    keyboard_symbol[1][1] = '4';
    keyboard_symbol[1][2] = '5';
    keyboard_symbol[1][3] = '@';
    keyboard_symbol[1][4] = '8';
    keyboard_symbol[1][5] = '7';
    keyboard_symbol[1][6] = NULL;

    keyboard_symbol[2][0] = '3';
    keyboard_symbol[2][1] = '/';
    keyboard_symbol[2][2] = '(';
    keyboard_symbol[2][3] = NULL;
    keyboard_symbol[2][4] = '?';
    keyboard_symbol[2][5] = '9';
    keyboard_symbol[2][6] = '6';

    keyboard_symbol[3][0] = '_';
    keyboard_symbol[3][1] = ':';
    keyboard_symbol[3][2] = ')';
    keyboard_symbol[3][3] = NULL;
    keyboard_symbol[3][4] = '!';
    keyboard_symbol[3][5] = ',';
    keyboard_symbol[3][6] = ';';

    keyboard_symbol[4][0] = '+';
    keyboard_symbol[4][1] = '"';
    keyboard_symbol[4][2] = '-';
    keyboard_symbol[4][3] = NULL;
    keyboard_symbol[4][4] = NULL;
    keyboard_symbol[4][5] = '.';
    keyboard_symbol[4][6] = '\'';

    delay(500);
    pinMode(keyborad_BL_PIN, OUTPUT);
    set_keyborad_BL(keyborad_BL_state);

    bleKeyboard.begin();

    for (int x = 0; x < rowCount; x++) {
        Serial.print(rows[x]); Serial.println(" as input");
        pinMode(rows[x], INPUT);
    }

    for (int x = 0; x < colCount; x++) {
        Serial.print(cols[x]); Serial.println(" as input-pullup");
        pinMode(cols[x], INPUT_PULLUP);
    }

    symbolSelected = false;


    TFT_099.begin();
    TFT_099.backlight(50);
    TFT_099.DispColor(0, 0, TFT_WIDTH, TFT_HEIGHT, BLACK);
    TFT_099.DrawImage(0, 0, 40, 160, liligo_logo);
    delay(2000);

    //Flow of the logo
    while (millis() < 6000) {
        for (int j = 0; j < 4; j++) {
            TFT_099.DrawImage(0, (160 - (flow_i + j * 55)), 40, 40, liligo_logo1);
        }
        flow_i++;
        if (flow_i == 55) {
            flow_i = 0;
        }
    }

        TFT_099.DispColor(0, 0, TFT_WIDTH, TFT_HEIGHT, BLACK);
    TFT_099.DispStr("version 1.0.0", 0, 2, WHITE, BLACK);
    delay(3000);

    TFT_099.DispColor(0, 0, TFT_WIDTH, TFT_HEIGHT, BLACK);
    TFT_099.DispStr("Wait bluetooth ......", 0, 2, WHITE, BLACK);
}


void loop()
{
    if (alt_active && keyPressed(3, 4)) {//alt+b   Change keyboard backlight status
        alt_active = false;
        TFT_099.DispColor(0, 0, TFT_HIGH, TFT_WIDE, BLACK);
        keyborad_BL_state = !keyborad_BL_state;
        set_keyborad_BL(keyborad_BL_state);
        clear_sccreen();
    }

    if (keyPressed(2, 3)) {  //Right Shit  ,Toggle case locking
        case_locking = !case_locking;
    }

    if (bleKeyboard.isConnected()) {
        if (millis() - previousMillis_1  > backlight_off_time) {//No keyboard for 20 seconds. Turn off the screen backlight
            TFT_099.backlight(0);
            previousMillis_1 = millis();;
        }

        if (display_connected) {
            TFT_099.backlight(50);
            TFT_099.DispStr("Bluetooth connected", 0, 2, WHITE, BLACK);
            display_connected = false;
        }

        readMatrix();
        printMatrix();

        // key 3,3 is the enter key
        if (keyPressed(3, 3)) {
            clear_sccreen();
            Serial.println();
            bleKeyboard.println();
        }
        //BACKSPACE
        if (keyPressed(4, 3)) {
            if (OffsetX < 8) {
                OffsetX = 0;
            } else {
                OffsetX = OffsetX - GAP;
            }

            TFT_099.DispColor(0, OffsetX, TFT_HIGH, TFT_WIDE, BLACK);
            bleKeyboard.press(KEY_BACKSPACE);
        }
        //SHIFT
        if (keyPressed(1, 6)) {
            bleKeyboard.press(KEY_RIGHT_SHIFT);
        }
        //alt+left shit, trigger ctrl+shift(Switch the input method)
        if (keyActive(0, 4) && keyPressed(1, 6)) {
            bleKeyboard.press(KEY_RIGHT_CTRL);
            bleKeyboard.press(KEY_RIGHT_SHIFT);
        }

        bleKeyboard.releaseAll();

    } else {
        if (millis() - previousMillis_2 > display_Wait_blue_time ) {
            TFT_099.DispColor(0, 0, TFT_WIDTH, TFT_HEIGHT, BLACK);
            TFT_099.DispStr("Wait bluetooth ......", 0, 2, WHITE, BLACK);
            display_connected = true;
            previousMillis_2 = millis();
        }
    }

}

// Keyboard backlit status
void set_keyborad_BL(bool state)
{
    digitalWrite(keyborad_BL_PIN, state);
}

void clear_sccreen()
{
    OffsetX = 0;
    TFT_099.DispColor(0, 0, TFT_WIDTH, TFT_HEIGHT, BLACK);
}

void readMatrix()
{


    int delayTime = 0;
    // iterate the columns
    for (int colIndex = 0; colIndex < colCount; colIndex++) {
        // col: set to output to low
        byte curCol = cols[colIndex];
        pinMode(curCol, OUTPUT);
        digitalWrite(curCol, LOW);

        // row: interate through the rows
        for (int rowIndex = 0; rowIndex < rowCount; rowIndex++) {
            byte rowCol = rows[rowIndex];
            pinMode(rowCol, INPUT_PULLUP);
            delay(1); // arduino is not fast enought to switch input/output modes so wait 1 ms

            bool buttonPressed = (digitalRead(rowCol) == LOW);

            keys[colIndex][rowIndex] = buttonPressed;
            if ((lastValue[colIndex][rowIndex] != buttonPressed)) {
                changedValue[colIndex][rowIndex] = true;
            } else {
                changedValue[colIndex][rowIndex] = false;
            }

            lastValue[colIndex][rowIndex] = buttonPressed;
            pinMode(rowCol, INPUT);
        }
        // disable the column
        pinMode(curCol, INPUT);
    }

    if (keyPressed(0, 2)) {
        symbolSelected = true;
        // symbolSelected = !symbolSelected;
    }

}

bool keyPressed(int colIndex, int rowIndex)
{
    return changedValue[colIndex][rowIndex] && keys[colIndex][rowIndex] == true;
}

bool keyActive(int colIndex, int rowIndex)
{
    return keys[colIndex][rowIndex] == true;
}

bool isPrintableKey(int colIndex, int rowIndex)
{
    return keyboard_symbol[colIndex][rowIndex] != NULL || keyboard[colIndex][rowIndex] != NULL;
}


void printMatrix()
{

    for (int rowIndex = 0; rowIndex < rowCount; rowIndex++) {
        for (int colIndex = 0; colIndex < colCount; colIndex++) {
            // we only want to print if the key is pressed and it is a printable character
            if (keyPressed(colIndex, rowIndex) && isPrintableKey(colIndex, rowIndex)) {

                String toPrint;
                if (symbolSelected) {
                    symbolSelected = false;
                    toPrint = String(keyboard_symbol[colIndex][rowIndex]);
                } else {
                    toPrint = String(keyboard[colIndex][rowIndex]);
                }

                if (keyActive(0, 4)) {
                    alt_active = true;
                    keys[0][4] = false;
                    return;
                }
                // keys 1,6 and 2,3 are Shift keys, so we want to upper case
                if (case_locking || keyActive(1, 6)) {
                    toPrint.toUpperCase();
                }


                TFT_099.DispColor(0, OffsetX, TFT_HIGH, TFT_WIDE, BLACK);
                char c[2];
                strcpy(c, toPrint.c_str());
                TFT_099.DispStr(c, OffsetX, 2, WHITE, BLACK);
                Serial.println(c);
                Serial.print(toPrint);
                bleKeyboard.print(toPrint);
                OffsetX = OffsetX + GAP;
                if (OffsetX > 160) {
                    OffsetX = 0;
                    TFT_099.DispColor(0, 0, TFT_HIGH, TFT_WIDE, BLACK);

                }
                TFT_099.backlight(50);
                previousMillis_1 = millis();

            }
        }
    }
}

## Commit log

2022-03-31 feature：T-keyboard
2022-05-06 perfect：
2022-05-07 test：Increase the sample ，To optimize the readme
2022-06-06 perfect：Support platformio.ini ,TFT_GC9D01N
2022-06-18 perfect：Add some keyboard shortcuts
    [BLE_keybord.ino]
2022-06-18 fix：Fixed the repairing issue
